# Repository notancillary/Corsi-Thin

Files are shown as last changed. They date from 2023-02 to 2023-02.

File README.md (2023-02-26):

# Corsi-Thin
A thin, quiet, serviceable, and scavengable Corsi-Rosenthol style air cleaner. <br>
<br>


<br>


<br>

Core design tenants: <br>
1. Use E-waste as much as possible <br>
2. Substantially reduce noise to allow for 24/7 operation in homes / workspaces <br>
4. Improve aesthetics, no tape etc, 3d printed parts <br>
5. Printed parts should be easy to print and not require supports <br>
6. Target cost below original Corsi-Rosenthol design <br>
7. Servicable with easily replacable filters <br>
8. Use filters that are often discounted and readily available (20x20x1) <br>

<br>

Required Materials: <br>
1. 1kg PETG or PLA. ($15) <br>
It is suggested to make the corner clips out of PETG as they are a snap-fit. <br>
<br>

2. 4x 120mm PC Fans <br>
These are easily scavenged from old PCs. If you cant find 120mm, you can easily adapt this design, or use an existing adapter such as this: <br>
https://www.thingiverse.com/thing:3020442<br>
If you need to buy new, here is an example: <br>
https://www.amazon.com/Apevia-CF512S-BK-120mm-Black-Silent/dp/B01BLVOC9Q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 <br>

<br>
3. 12v 2A or greater DC power brick. <br>
These can be scavenged from old appliances and electronics.<br>
If you need to buy new, here is an example: <br>
https://www.amazon.com/100-240V-Transformers-Switching-Applications-Connectors/dp/B077PW5JC3 <br>
<br>

4. 24x M4x30mm+ screws. OR #8-32x1-1/4" screws. ($5) <br>
English is easier and cheaper to find localy: <br>
https://www.lowes.com/pd/Hillman-8-32-x-1-1-2-in-Phillips-Drive-Machine-Screws-10-Count/3816115 <br>
Or online: <br>
https://www.amazon.com/Chinese-Handles-Phillips-Machine-Cabinet/dp/B098R1KR6J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<br>

5. 2x of your 20x20x1 filter of choice. ($12) <br>
Ex: <br>
https://www.lowes.com/pd/Filtrete-1900-MPR-Maximum-Allergen-Common-20-in-x-20-in-x-1-in-Actual-19-6-in-x-19-6-in-x-0-7809-in-Electrostatic-Pleated-Air-Filter/3130393 <br>
<br>

Printed parts:<br>
1. Fan Air Guides: (4x)<br>
<br>
1. Fan Panel Type 1: (1x)<br>
<br>
2. Fan Panel Type 2: (1x)<br>
<br>
3. Blank Panel Type 1: (3x)<br>
<br>
4. Blank Panel Type 2: (3x)<br>
<br>
5. Corner Clips: (8x)<br>
<br>
6. Apex Seals: (4x)<br>
<br>
<br>
<br>

<br>
Printing notes: <br>

All parts will fit on a prusa printer.. or any printer with a 250mm wide bed. <br>

<br>
Any infill is fine for the panels, but for the clips it is good to use at least 3 walls. <br>
Each panel is about 100g of material, the project target was to be completed within one spool and this is easily achievable with normal print settings. <br>
<br>

General notes: <br>
The air guides on the fans are not required. They do improve noise and prevent recirculation however for a better overall system efficiency. <br>
Step files are provided if you want to modify the design.<br>
Expect around 200-400CFM with a merv 13 filter depending on the fans you have sourced. 
<br>

<br>

CC BY-NC-SA 3.0

<br />This work is licensed under a <a rel="license" href="http://creativecommons.org/licenses/by-nc-sa/3.0/">Creative Commons Attribution-NonCommercial-ShareAlike 3.0 Unported License</a>.

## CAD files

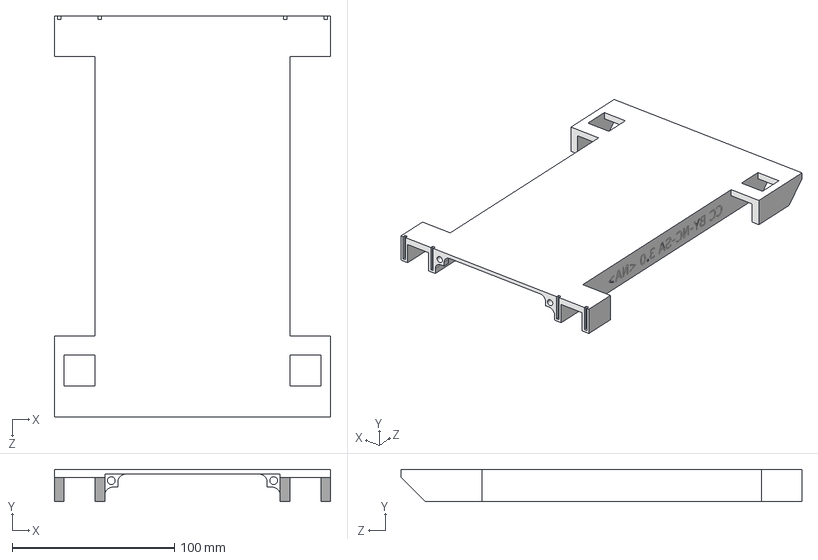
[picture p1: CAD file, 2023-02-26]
Blank Panel 2.STEP
170.1 x 20.0 x 247.0 mm

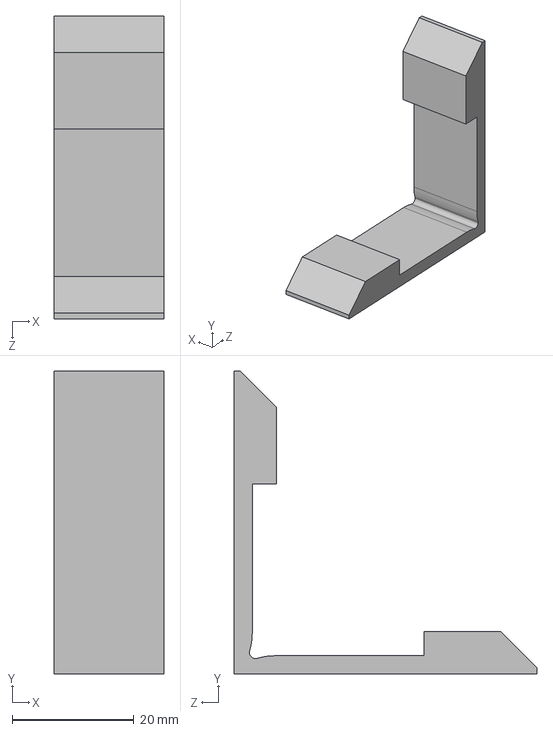
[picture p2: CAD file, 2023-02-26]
Corner Clip.STEP
18.0 x 49.7 x 49.7 mm

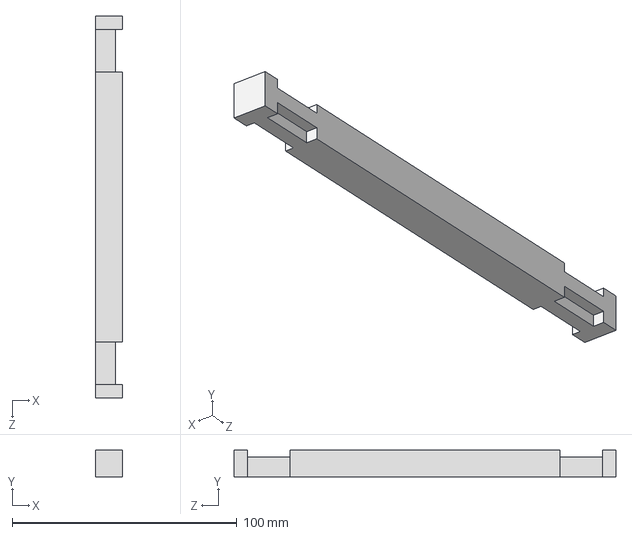
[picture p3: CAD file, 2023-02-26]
Apex Seal.STEP
11.8 x 11.8 x 170.0 mm

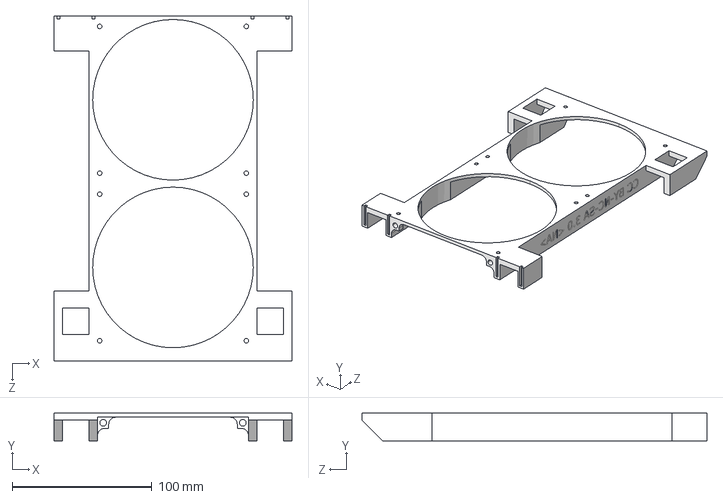
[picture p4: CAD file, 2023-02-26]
Fan Panel 2.STEP
170.1 x 20.0 x 247.0 mm

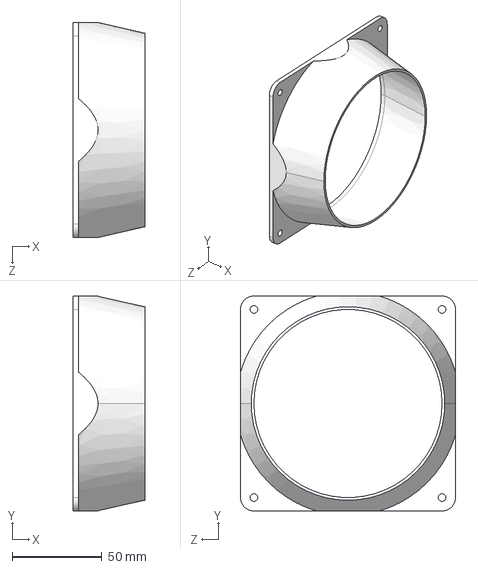
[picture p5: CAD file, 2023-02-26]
Air Guide.STEP
40.0 x 120.0 x 120.0 mm

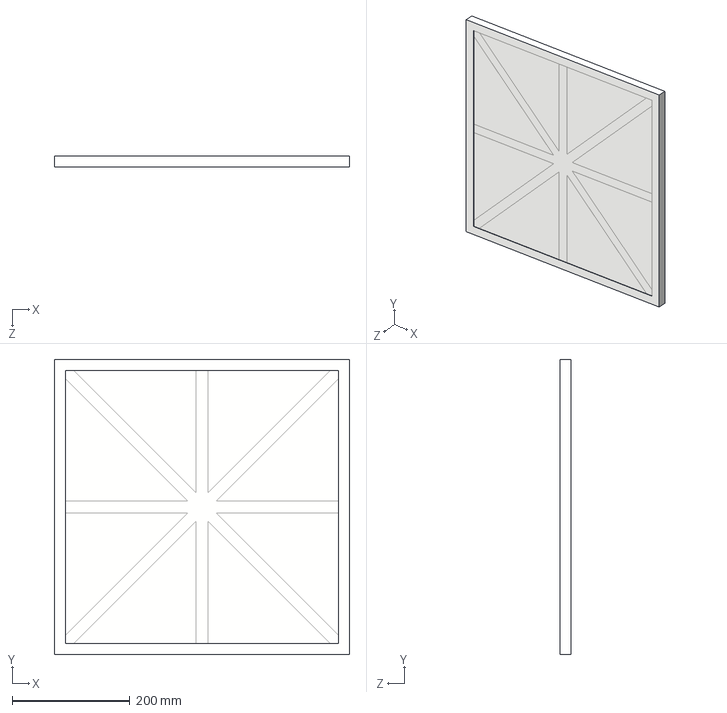
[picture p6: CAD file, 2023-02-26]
20x20x1 Filter Model.STEP
501.7 x 501.7 x 19.1 mm

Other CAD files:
Panel type 1.STEP
Fan Panel 1.STEP
Blank Panel 1.STEP
Air Guide.STL
Apex Seal.STL
Blank Panel 1.STL
Blank Panel 2.STL
Corner Clip.STL
Fan Panel 1.STL
Fan Panel 2.STL
